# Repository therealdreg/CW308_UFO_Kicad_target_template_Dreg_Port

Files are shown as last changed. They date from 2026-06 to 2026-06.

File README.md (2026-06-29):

# CW308_UFO_target_template_Dreg_Port

chipwhisper UFO CW308 TARGET template for KiCad with Dreg port (and easyeda file to import)

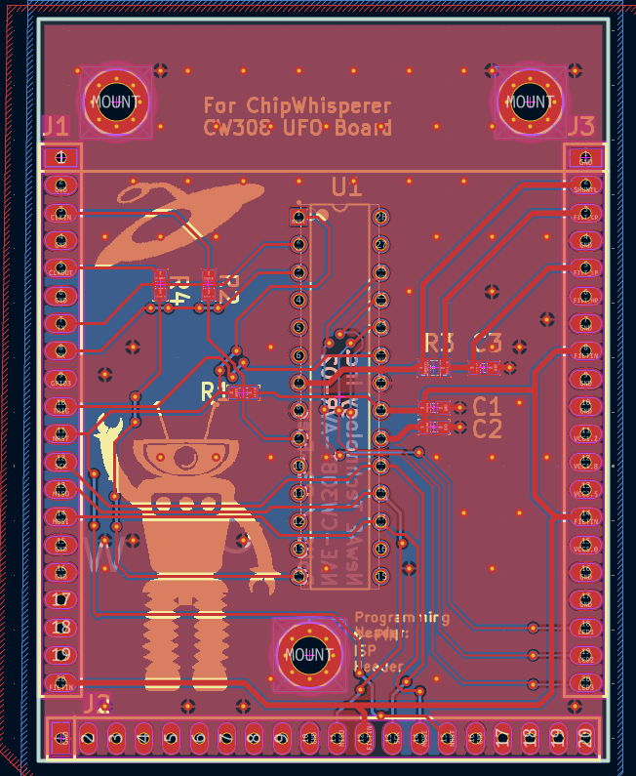
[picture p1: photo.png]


-----

# PCB

- ENIG
- PCB Size: 52.3mm x 64.6mm
- 2 layers
- male pins 

UFO BOARD SOCKET FEMALE:

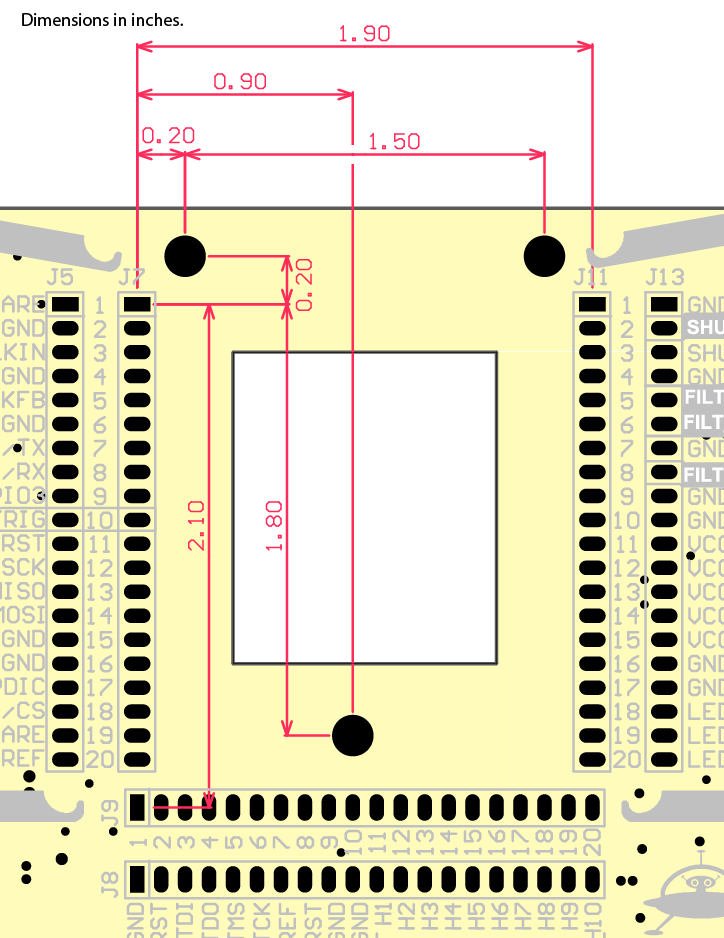
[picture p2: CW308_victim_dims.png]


-----

# MALE PINS

- 800-10-020-10-001101
- Preci-dip
- https://www.mouser.es/ProductDetail/437-8001002010001101

-----

# FEMALE PINS
- 801-87-020-10-001101
- Preci-dip
- https://www.mouser.es/ProductDetail/437-8018702010001101

------

# kicad project 

[CW308T_AVR_Kicad_Dreg_Port.zip](CW308T_AVR_Kicad_Dreg_Port.zip)

------

# easyeda pro file to import

[ProPrj_CW308T_AVR_Kicad_Dreg_Port_2026-06-29.epro2](ProPrj_CW308T_AVR_Kicad_Dreg_Port_2026-06-29.epro2)

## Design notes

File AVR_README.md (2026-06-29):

# CW308T-AVR

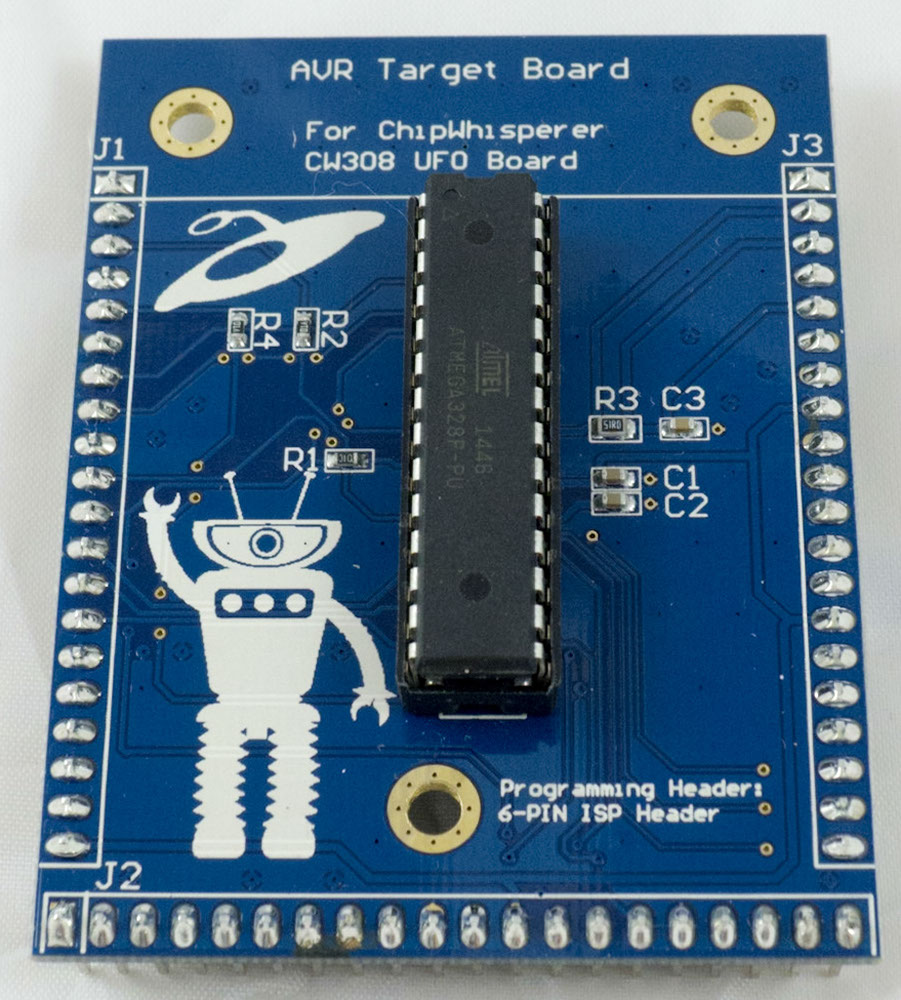
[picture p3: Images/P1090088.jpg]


---

## Specifications

| Feature | Notes/Range |
|---|---|
| Target Device | Atmel AVR |
| Target Architecture | 8-bit Harvard |
| Vcc | 3.3V |
| Programming | ISP |
| Hardware Crypto | No |
| Availability | Standalone |
| Status | Discontinued |
| Shunt | 51Ω |

This target used to come with many of NewAE's starter kits, but has been replaced with the CW308T-STM32F3.

## I/O Connections

**NOTE:** The serial pins for this target are swapped compared to the usual setup. An example setup script can be found here: https://github.com/newaetech/chipwhisperer-jupyter/blob/1ccd1b1fbd8a3295e1033efb37e53e1022d47cc5/Helper_Scripts/Setup_Notduino.ipynb

The pinout of this module matches the "NOTDuino" kit along with the
"CW301 Multi-Target Board" routing. The following is the connection
between GPIO1-4 and the I/O lines on the AVR:

| **CW308 Pin** | **ATMega328P Pin** | **Notes** |
| --- | --- | --- |
| GPIO1 | PD0 (RXD) | Serial INPUT to AVR. |
| GPIO2 | PD1 (TXD) | Serial OUTPUT from AVR. |
| GPIO3 | N/C | |
| GPIO4 | PC0 | Trigger pin (mapped to ADC-port such that I/O driver power comes from AVCC). |
| CLKIN | XTAL1 | |
| CLKFB | PB0 | Can set this pin as CLKO with fuse. Useful for synchronizing to internal RC oscillator. |
| nRST | nRST (PC6) | Used by in-system-programming (ISP) interface. |
| MOSI | PB3 (MOSI) | Used by in-system-programming (ISP) interface. |
| MISO | PB4 (MISO) | Used by in-system-programming (ISP) interface. |
| SCK | PB5 (SCK) | Used by in-system-programming (ISP) interface. |

---

## Programming Header

The 6-pin programming heading can be used with the Atmel ISP interface.
The pinout of the 6-pin programming header on the main-board allows it
to work with standard Atmel ISP tools:

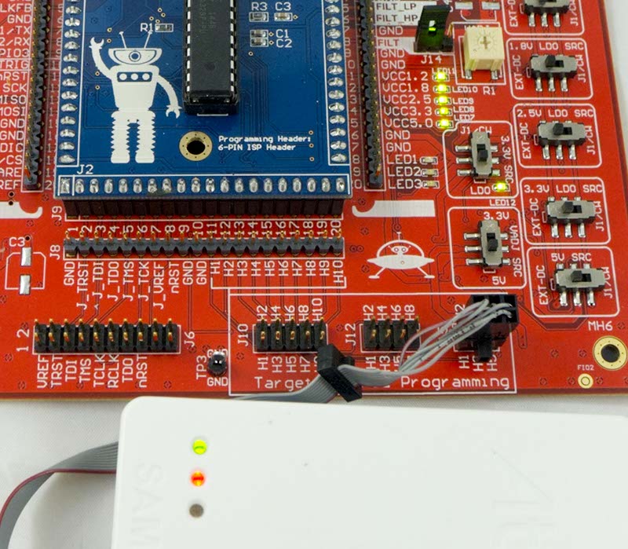
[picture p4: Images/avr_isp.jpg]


---

## Schematic

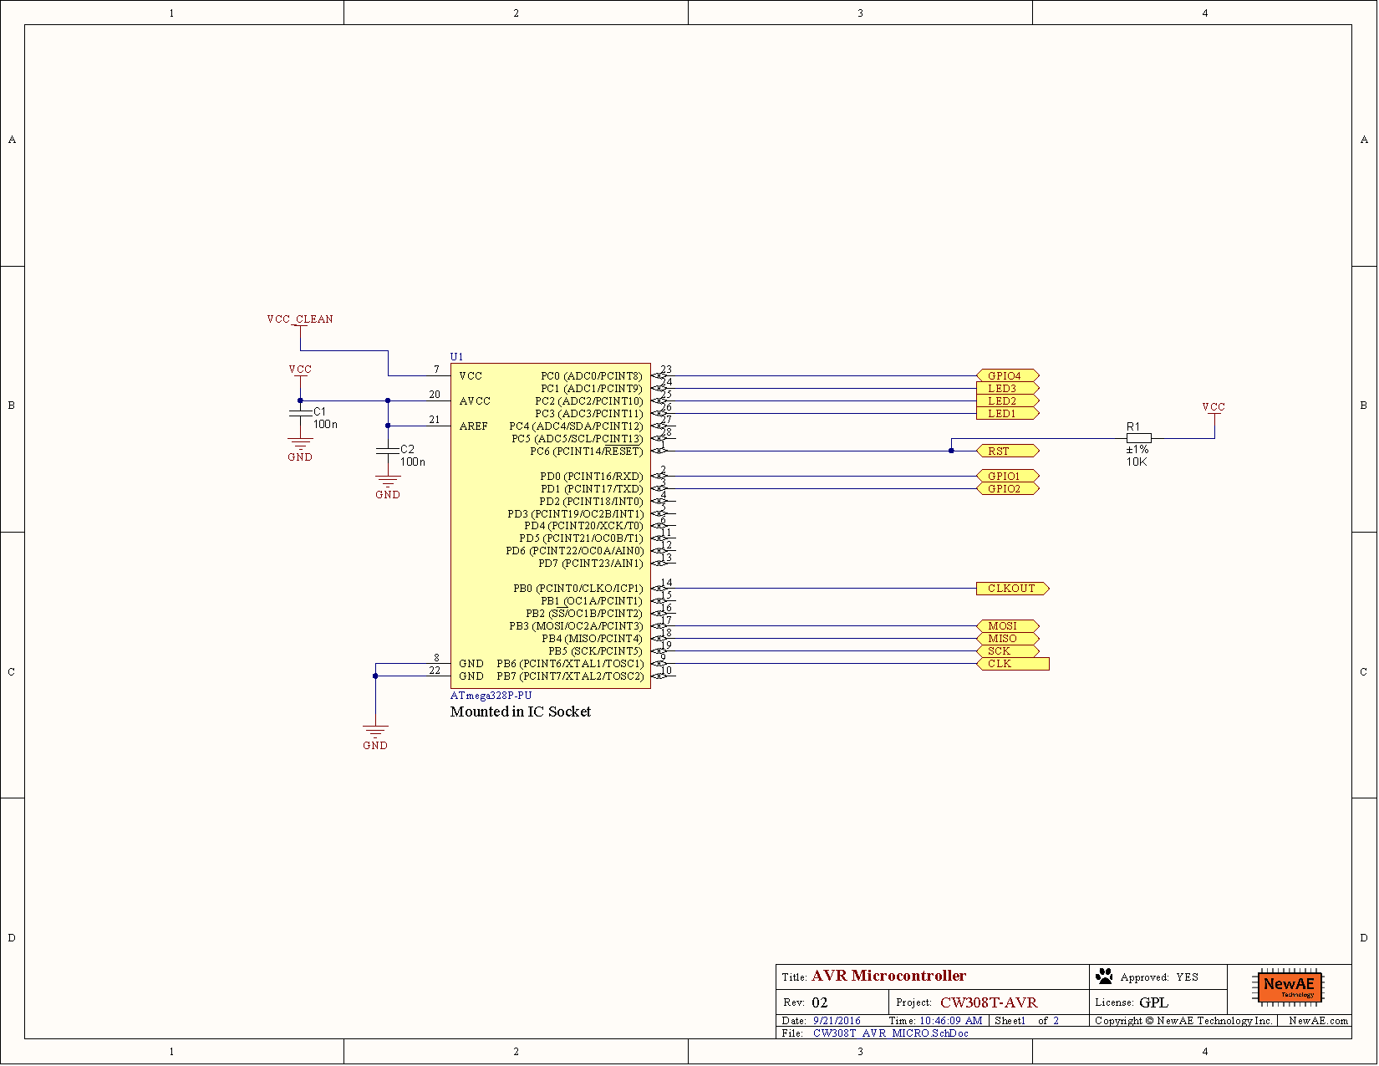
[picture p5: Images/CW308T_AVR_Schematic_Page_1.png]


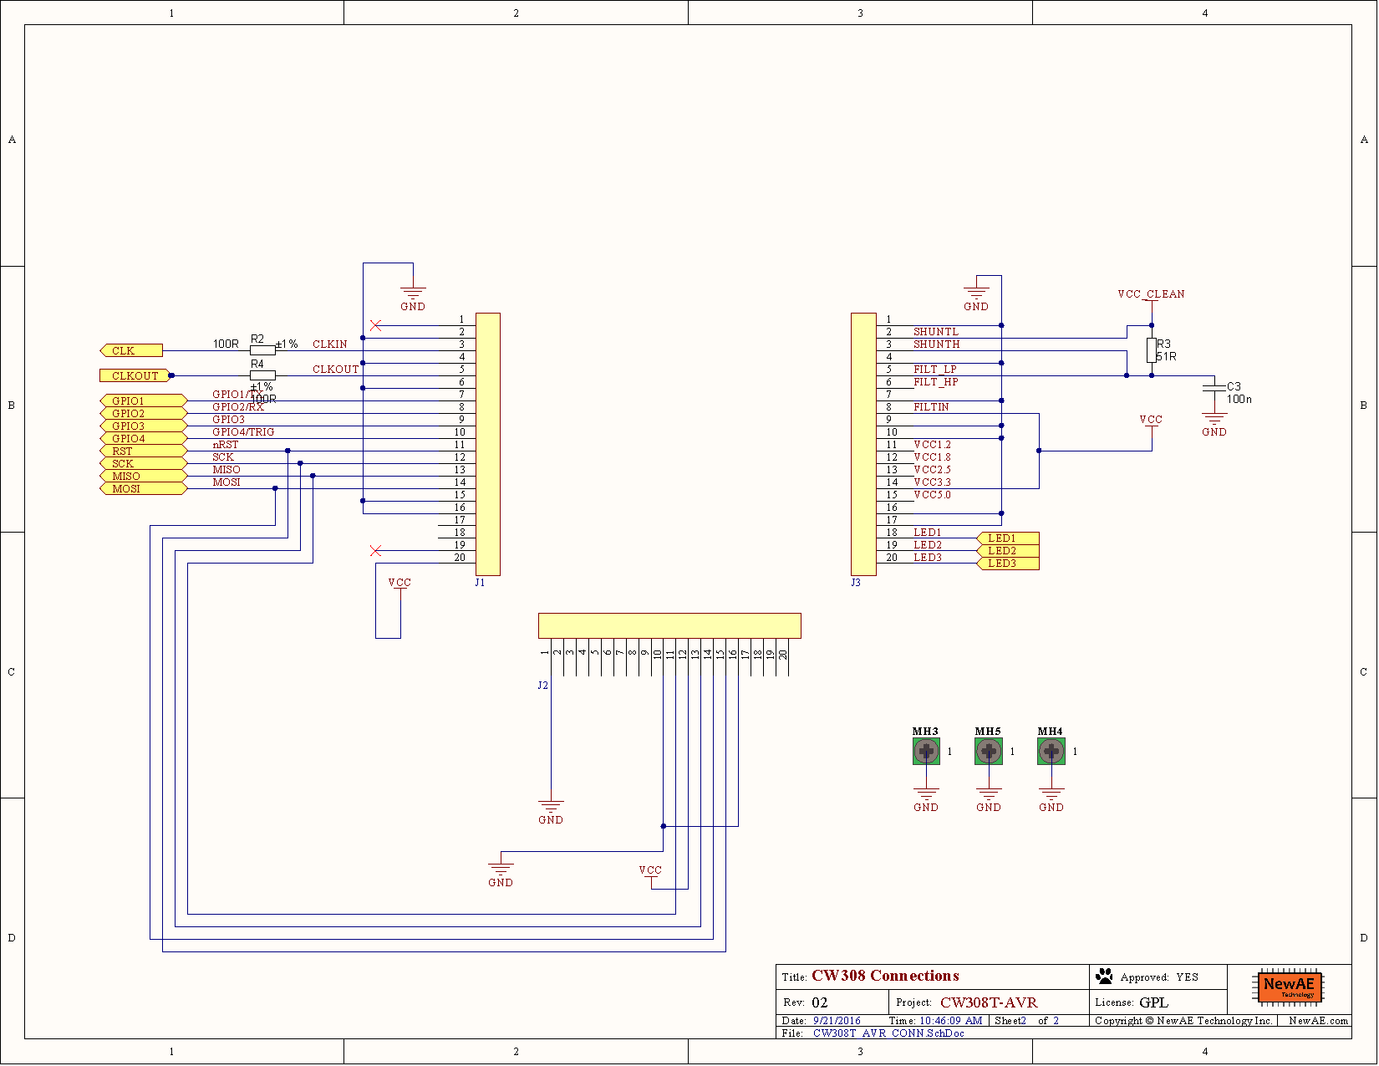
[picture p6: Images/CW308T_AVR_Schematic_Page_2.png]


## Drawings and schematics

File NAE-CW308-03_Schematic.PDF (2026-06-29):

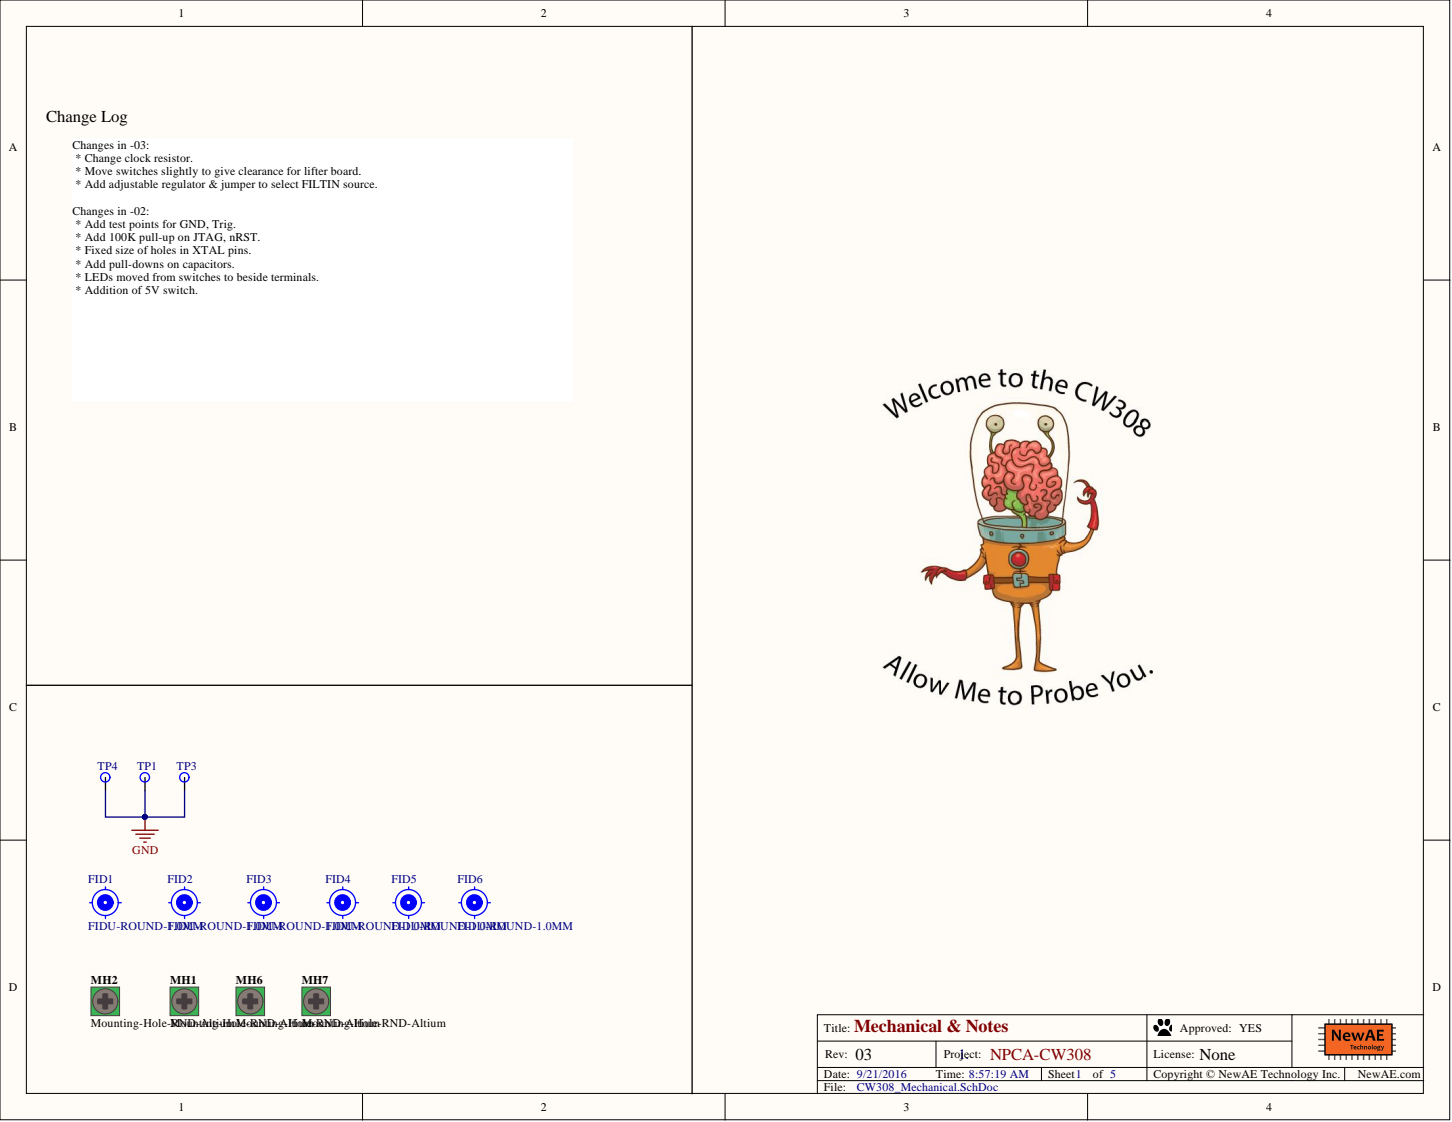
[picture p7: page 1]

Changes in -03:
* Change clock resistor.
* Move switches slightly to give clearance for lifter board.
* Add adjustable regulator & jumper to select FILTIN source.

Changes in -02:
* Add test points for GND, Trig.
* Add 100K pull-up on JTAG, nRST.
* Fixed size of holes in XTAL pins.
* Add pull-downs on capacitors.
* LEDs moved from switches to beside terminals.
* Addition of 5V switch.

Mounting-Hole-RND-Altium

Mechanical & Notes Title: | Approved: YES

Rev: 03 | Project: NPCA-CW308 | License: None

Date: 9/21/2016 Time: 8:57:19 AM | Sheet of

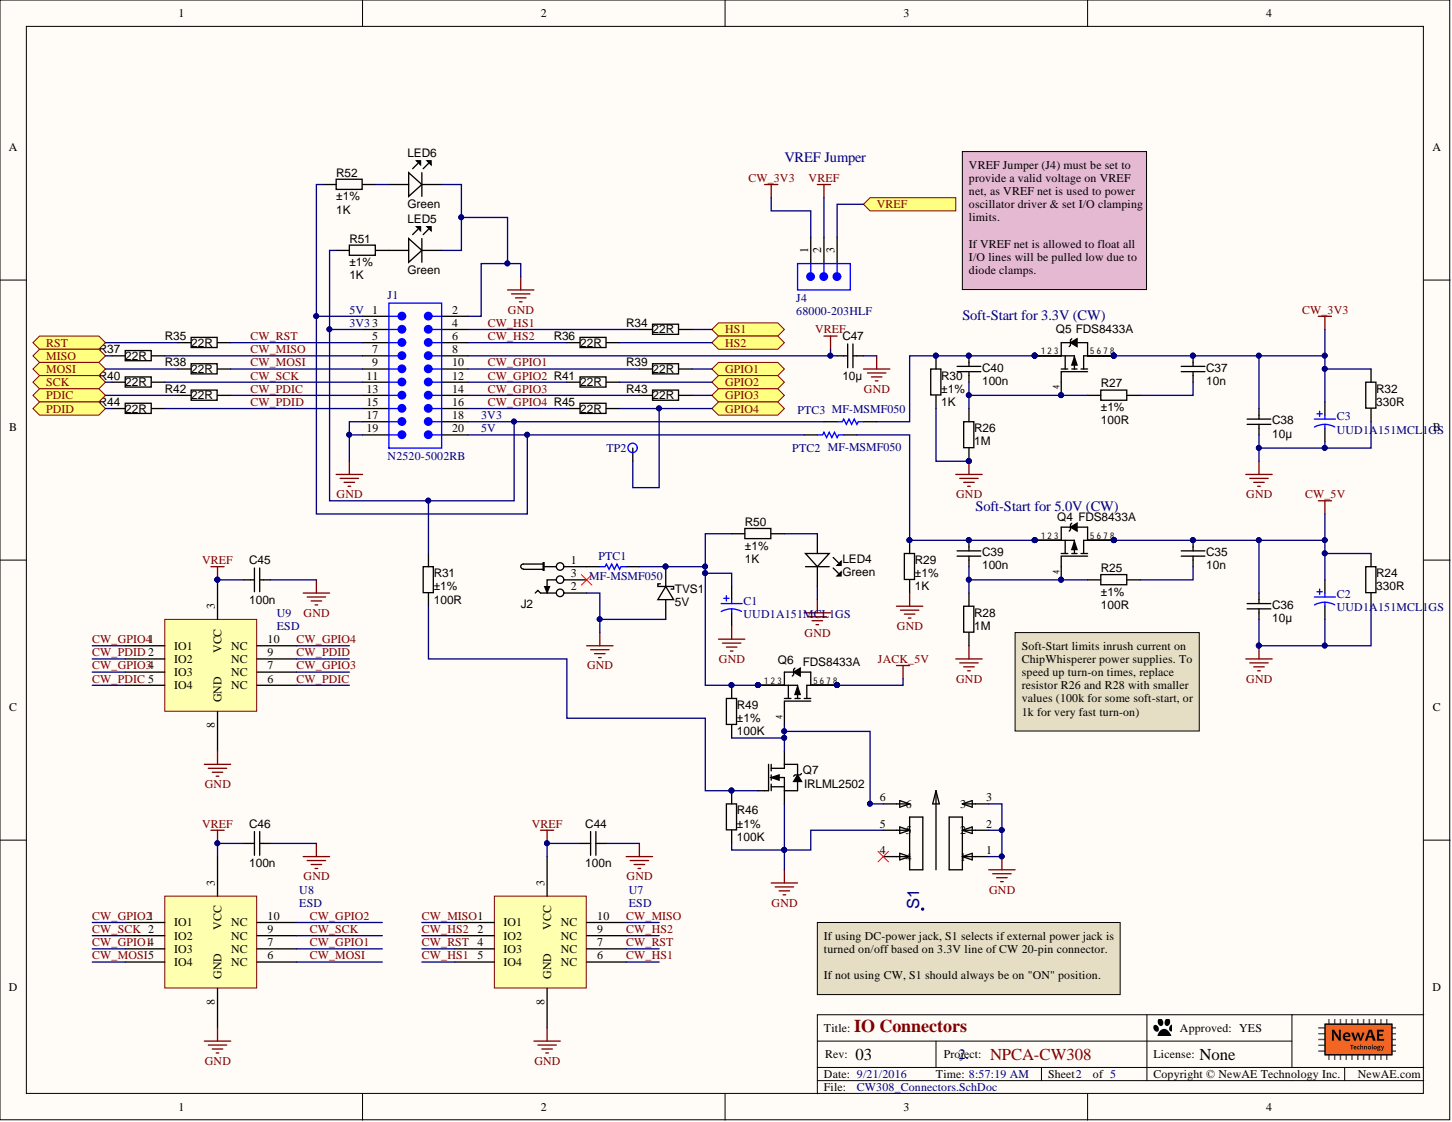
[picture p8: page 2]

provide a valid voltage on VREF
net, as VREF net is used to power
oscillator driver & set I/O clamping
limits.

If VREF net is allowed to float all
I/O lines will be pulled low due to
diode clamps.

Soft-Start for 3.3V (CW)

GND
Soft-Start for 5.0V (CW)

Soft-Start limits inrush current on
ChipWhisperer power supplies. To
speed up turn-on times, replace
resistor R26 and R28 with smaller
values (100k for some soft-start, or
1k for very fast turn-on)

If using DC-power jack, S1 selects if external power jack is
turned on/off based on 3.3V line of CW 20-pin connector.

If not using CW, S1 should always be on "ON" position.

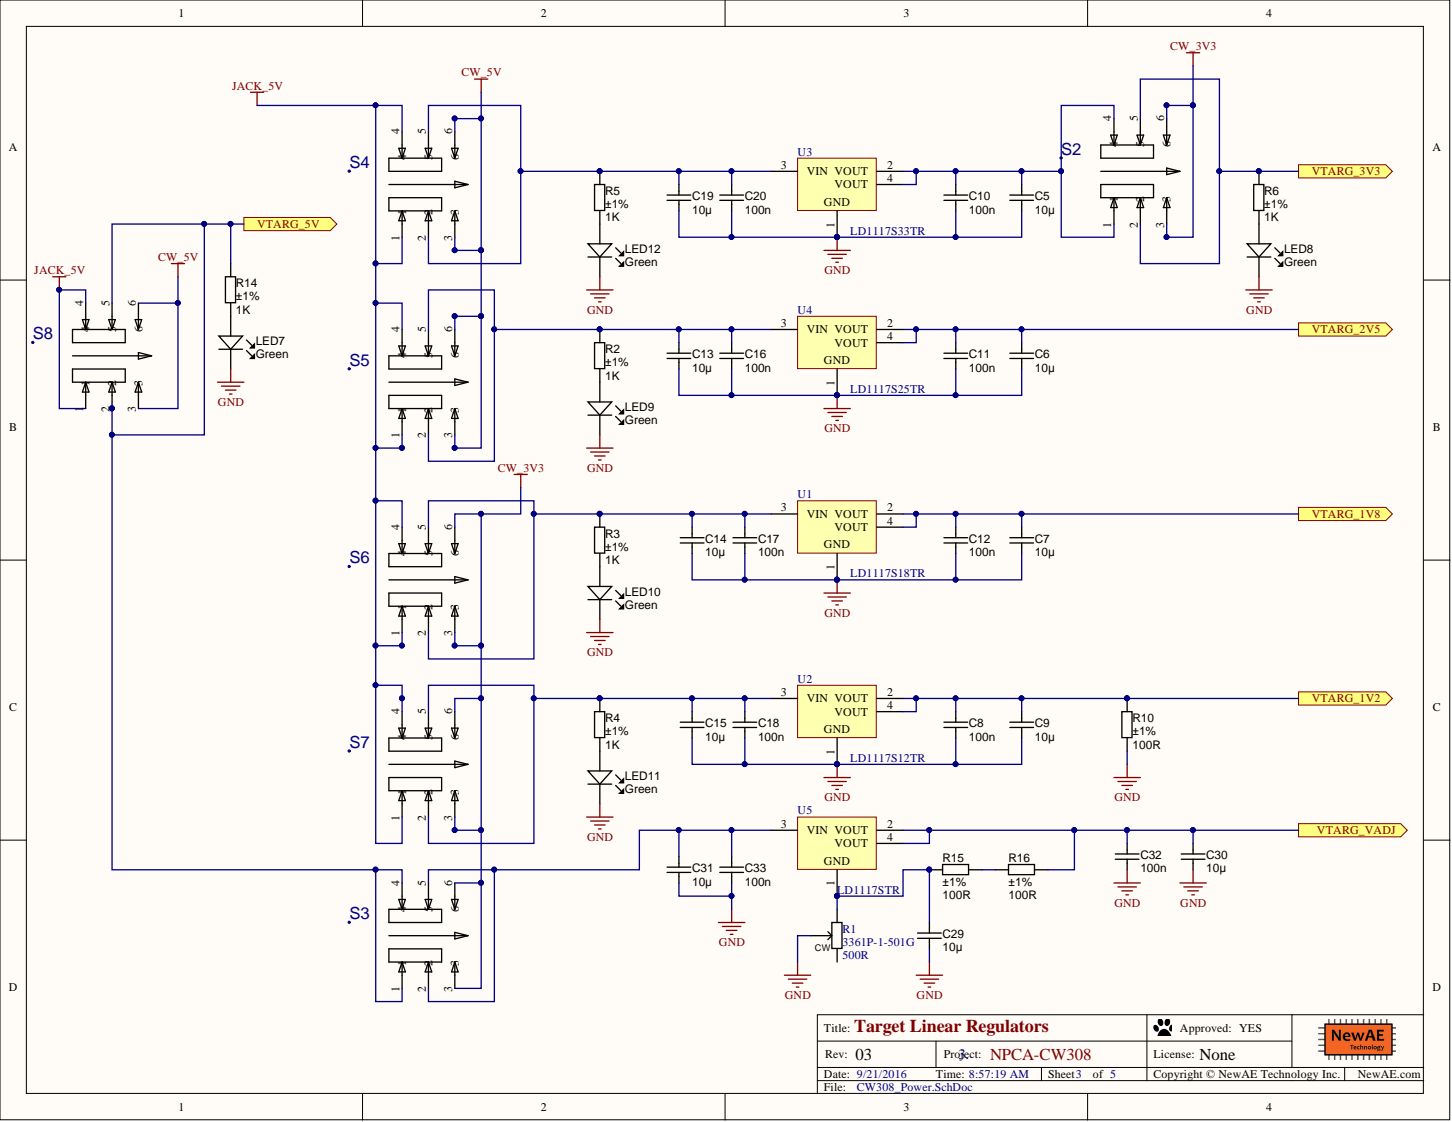
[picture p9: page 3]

T i t le: | A p pro ved : Y E S

Rev : 03 | Project : NPCA-CW308 | L icen se: None

T ime: | Sheet o f | Co p yri g h t © New A E Tech n | o l o g y Inc.

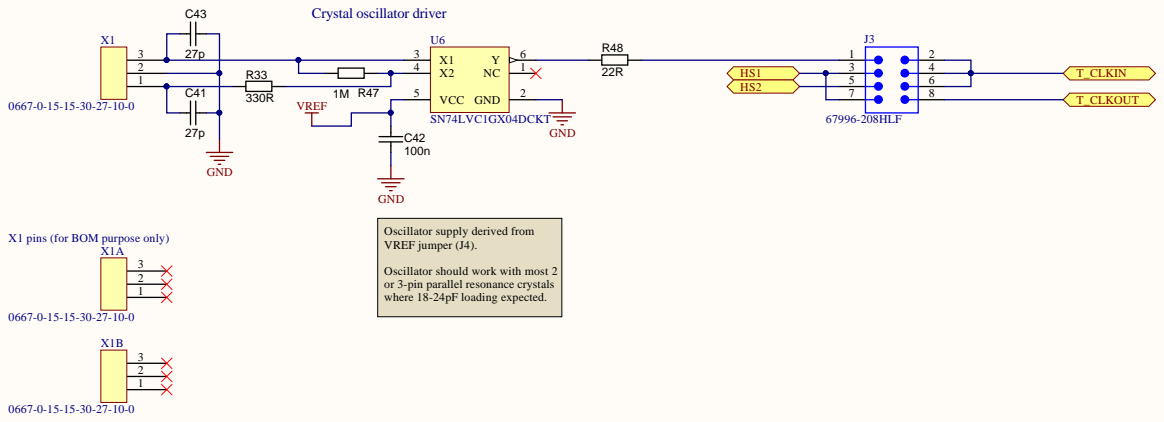
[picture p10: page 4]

Oscillator supply derived from
VREF jumper (J4).

X1 pins (for BOM purpose only)

Oscillator should work with most 2
or 3-pin parallel resonance crystals
where 18-24pF loading expected.

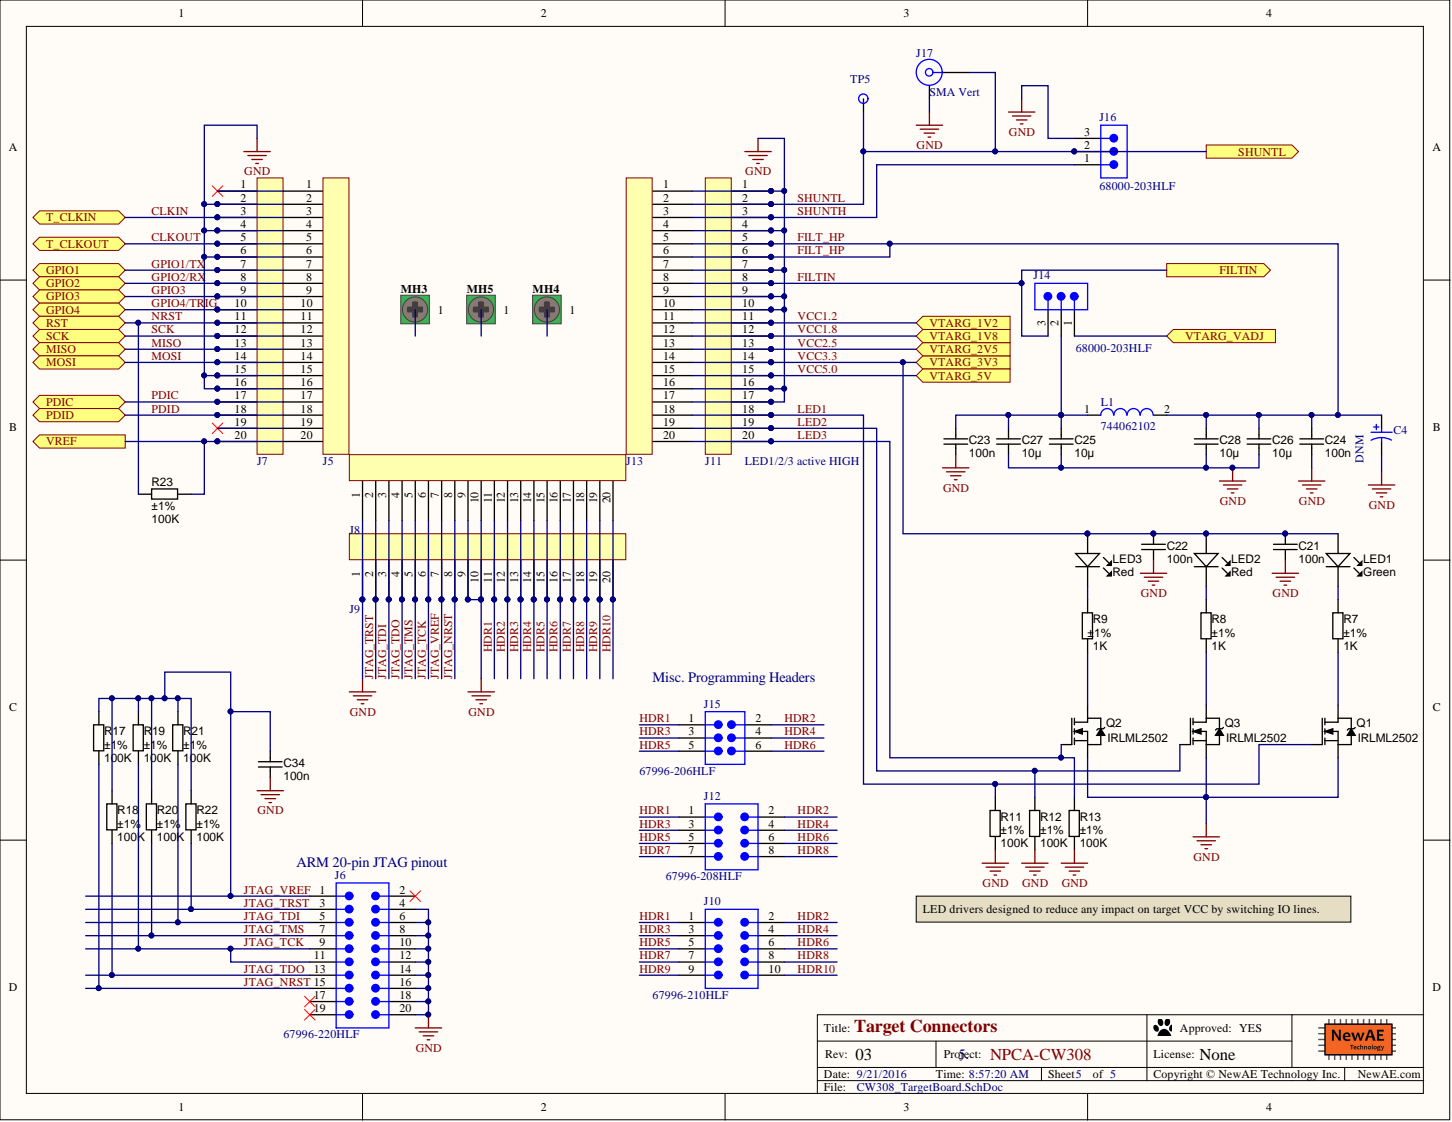
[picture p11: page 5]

9 | 9 | VCC1.2 VTARG_1V2
10 | 10
11 | 11
12 | 12 | VCC1.8
13 | 13 | VCC2.5
14 | 14 | VCC3.3
15 | 15 | VCC5.0

17 | | 17
18 | | 18
19 | 19 LED2
20 | 20 LED3

ARM 20-pin JTAG pinout

LED drivers designed to reduce any impact on target VCC by switching IO lines.

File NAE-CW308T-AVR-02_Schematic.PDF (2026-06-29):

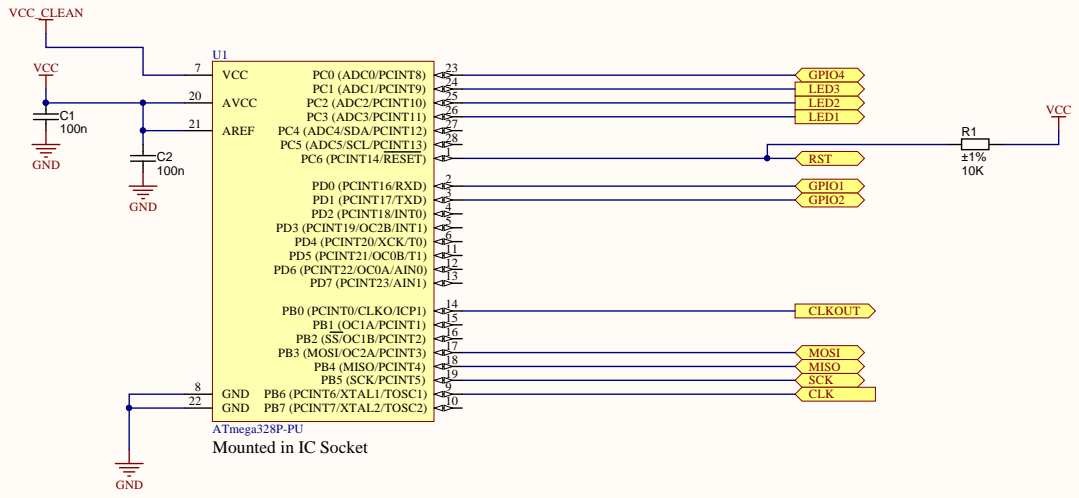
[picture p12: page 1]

A V R Microcontroller T i t le: | A p pro ved : Y E S

Rev : 02 | Project : CW308T-A V R | L icen se: GPL

Date: 9 / 2 1 / 2 0 1 6 T ime: 1 0 : 4 6 : 0 9 A M | Sheet 1 o f 2 | Co p yri g h t © New A E Tech n | o l o g y Inc.

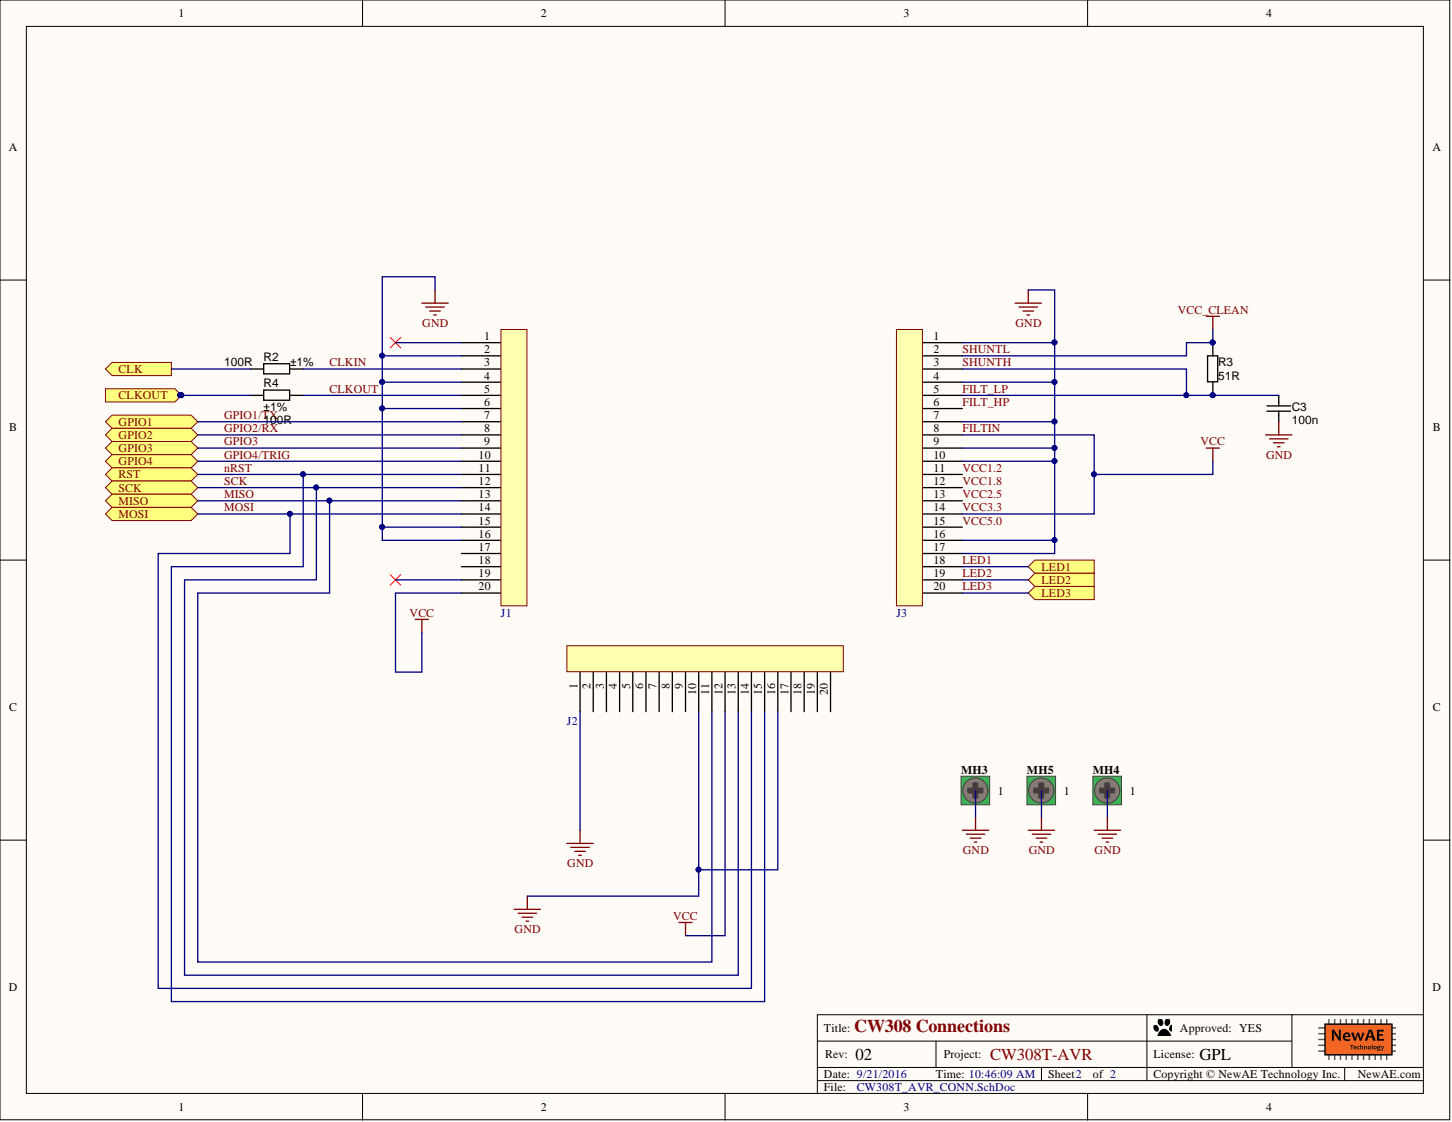
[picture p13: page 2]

SH U N T L
SH U N T H

FIL T _ L P
FIL T _ H P

FIL TIN

CW3 0 8 C onnections T i t le: | A p pro ved : Y E S

Rev : 02 | Project : CW308T-A V R | L icen se: GPL

Date: 9 / 2 1 / 2 0 1 6 T ime: 1 0 : 4 6 : 0 9 A M | Sheet 2 o f 2 | Co p yri g h t © New A E Tech n | o l o g y Inc.

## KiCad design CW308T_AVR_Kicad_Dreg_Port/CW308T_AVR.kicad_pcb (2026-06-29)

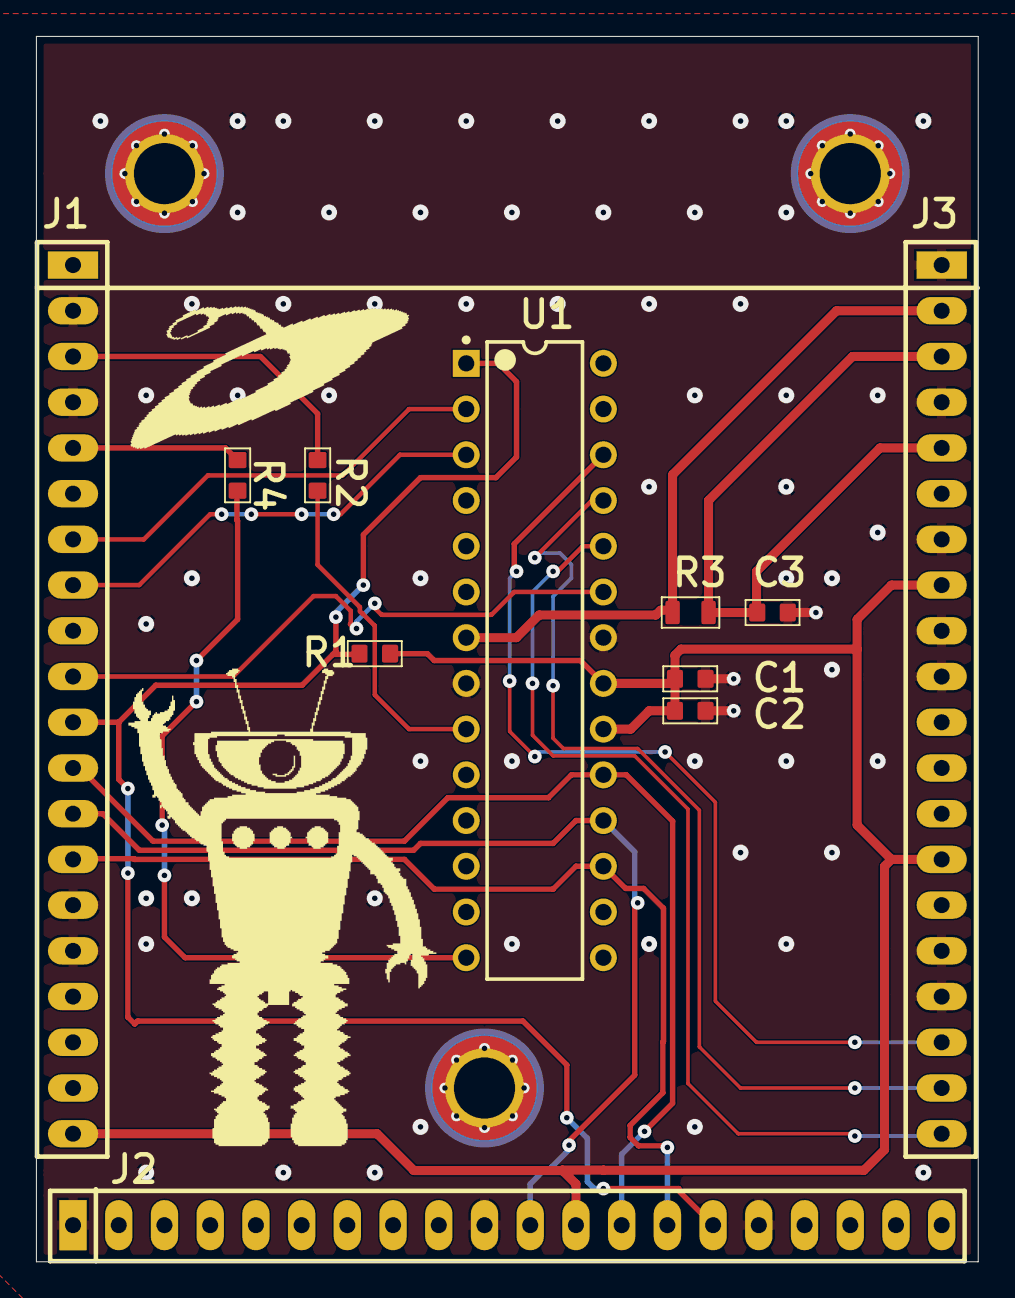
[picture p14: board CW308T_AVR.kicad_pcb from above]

Board: 2 copper layers, 52.3 x 68.1 mm, 14 parts (0 on the bottom side), 18 nets.

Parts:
C1, C2, C3: approved sub OK; CAPC1608X90N
J1, J2, J3: 20-Pin Header; 801-87-020-10-001101
MH3, MH4, MH5: Mounting-Hole-RND-Altium
R1, R2, R4: Thick Film; RESC1608X55N
R3: Thick Film; RESC2012X70N
U1: ATmega328P-PU; 28P3

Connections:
CLKIN: J1.3, R2.2
CLKOUT: J1.5, R4.2
FILTIN: C1.1, C2.1, J1.20, J2.12, J3.8, J3.14, R1.1, U1.20, U1.21
FILT_LP: C3.1, J3.3, J3.5, R3.2
GND: C1.2, C2.2, C3.2, J1.2, J1.4, J1.6, J1.15, J1.16, J2.1, J2.10, J2.16, J3.1, J3.4, J3.7, J3.9, J3.10, J3.16, J3.17, U1.8, U1.22
GPIO1/TX: J1.7, U1.2
GPIO2/RX: J1.8, U1.3
GPIO4/TRIG: J1.10, U1.23
LED1: J3.18, U1.26
LED2: J3.19, U1.25
LED3: J3.20, U1.24
MISO: J1.13, J2.11, U1.18
MOSI: J1.14, J2.14, U1.17
NRST: J1.11, J2.15, R1.2, U1.1
NetR2_1: R2.1, U1.9
NetR4_1: R4.1, U1.14
SCK: J1.12, J2.13, U1.19
SHUNTL: J3.2, R3.1, U1.7

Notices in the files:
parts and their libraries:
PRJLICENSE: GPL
